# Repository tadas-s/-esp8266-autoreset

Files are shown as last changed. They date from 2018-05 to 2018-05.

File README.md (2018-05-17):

# FTDI cable adapter with dtrset reset method

Schematic taken from [this blog post][1]. The only small difference is output header pins drops
CTS and RTS pins and replaces with FLASH and RESET signals.

So board input is a standard FTDI 6 pin cable and output is:

    pin 1 -> GND
    pin 2 -> FLASH (to be connected to GPIO0)
    pin 3 -> VCC
    pin 4 -> TXD
    pin 5 -> RXD
    pin 6 -> RESET (to be connected to reset pin)

Project mentioned above exposes FLASH and RESET as a separate 2 pin header.

Schematic preview:

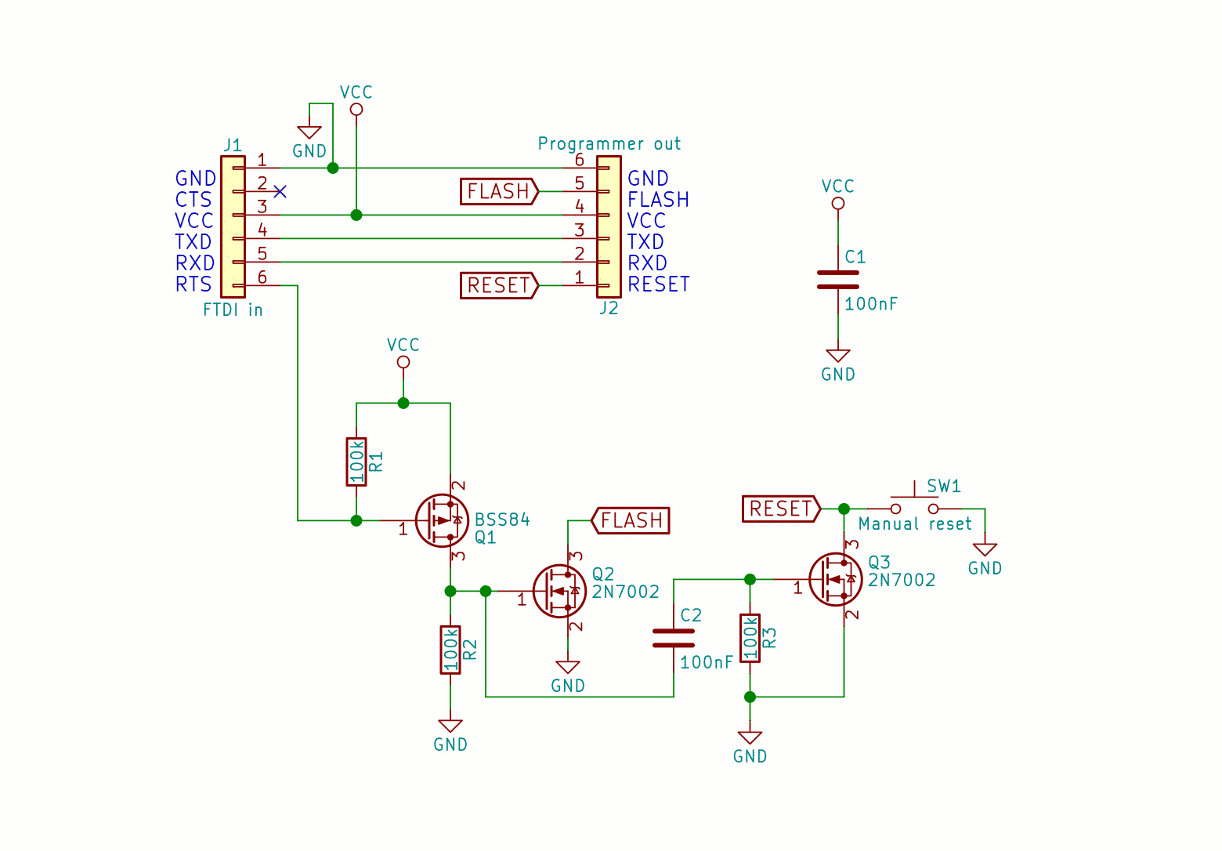
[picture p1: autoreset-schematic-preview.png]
schematic preview


Complete and tested board:

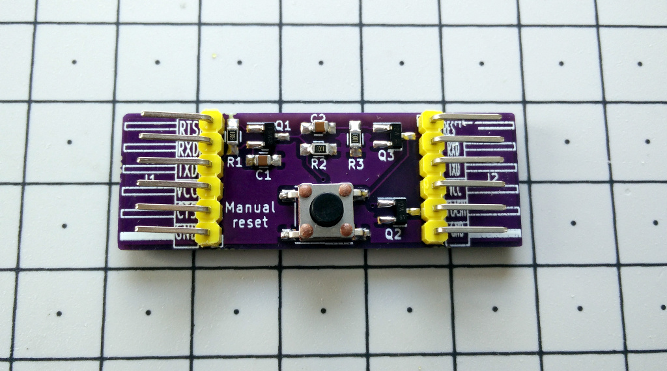
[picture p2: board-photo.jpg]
board


Schematic captured and PCB done using the amazing [KiCad][1]!.

[1]: http://www.jce.lu/blog/?p=143 
[2]: autoreset-schematic-preview.png
[3]: board-photo.jpg
[4]: http://kicad-pcb.org/

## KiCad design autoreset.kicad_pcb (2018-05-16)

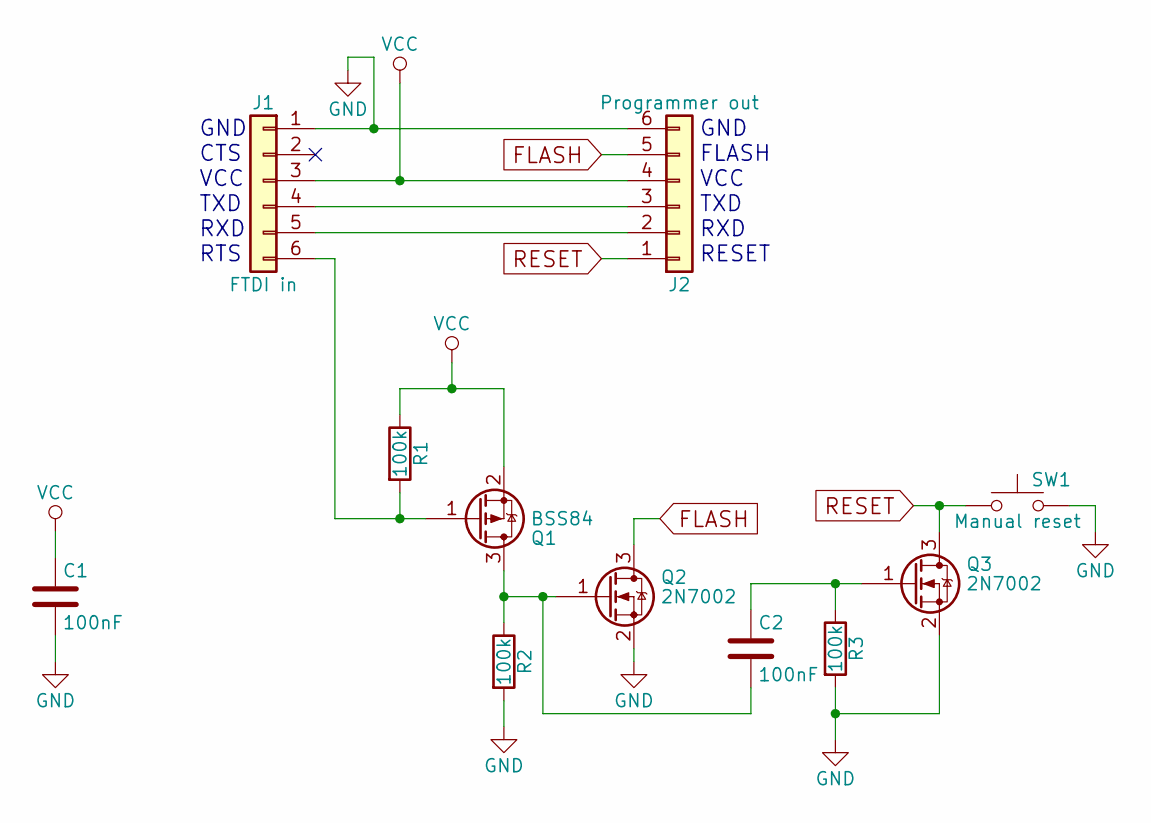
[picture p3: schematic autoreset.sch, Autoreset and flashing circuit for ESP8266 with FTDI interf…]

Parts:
C1, C2: 100nF; C_0805_HandSoldering
J1: FTDI in; Pin_Header_Angled_1x06_Pitch2.54mm
J2: Programmer out; Pin_Header_Angled_1x06_Pitch2.54mm
Q1: BSS84; SOT-23_Handsoldering
Q2, Q3: 2N7002; SOT-23_Handsoldering
R1, R2, R3: 100k; R_0805_HandSoldering
SW1: Manual reset; SW_SPST_PTS645

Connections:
FLASH: J2.5, Q2.3 (D)
GND: C1.2, J1.1, J2.6, Q2.2 (S), Q3.2 (S), R2.2, R3.2, SW1.2
unnamed: C2.1, Q3.1 (G), R3.1
unnamed: C2.2, Q1.3 (D), Q2.1 (G), R2.1
unnamed: J1.4, J2.3
unnamed: J1.5, J2.2
unnamed: J1.6, Q1.1 (G), R1.2
RESET: J2.1, Q3.3 (D), SW1.1
VCC: C1.1, J1.3, J2.4, Q1.2 (S), R1.1

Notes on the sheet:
GND CTS VCC TXD RXD RTS
GND FLASH VCC TXD RXD RESET

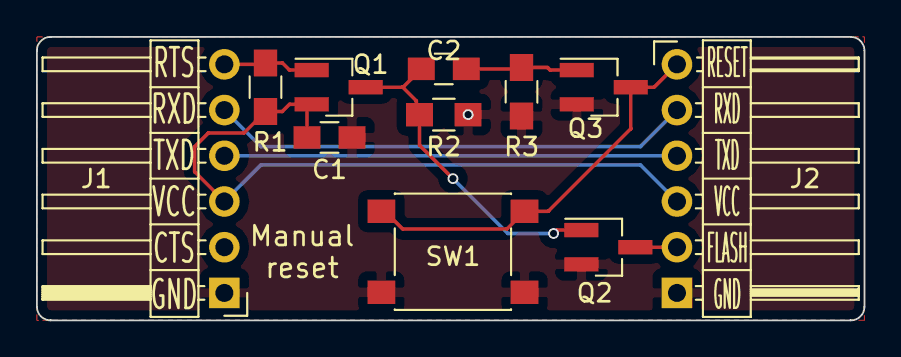
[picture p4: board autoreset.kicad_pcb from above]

Board: 2 copper layers, 46.0 x 15.7 mm, 11 parts (0 on the bottom side), 9 nets.

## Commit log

2018-05-16 ESP8266 programmer with auto-reset
    [autoreset.kicad_pcb, autoreset.sch]
2018-05-17 Moving around some stuff to look nicer, no real change
    [autoreset.sch]
